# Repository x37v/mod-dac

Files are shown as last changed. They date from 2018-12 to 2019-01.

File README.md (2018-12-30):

# MOD-DAC

An 8 channel DAC Schematic/PCB project intended for modular use.
It should be able to give -5..5 or 0..5 or some other range within that.
It is intended to be driven by 3.3v signals from a micro controller, not included in this project.

This project is adapted from the [Mutable Instruments "Stages"](https://mutable-instruments.net/modules/stages/open_source/).
Thank you to [O. Gillet](https://mutable-instruments.net).

## License

<br /><span xmlns:dct="http://purl.org/dc/terms/" property="dct:title">MOD-DAC</span> by <a xmlns:cc="http://creativecommons.org/ns#" href="https://github.com/x37v/mod-dac" property="cc:attributionName" rel="cc:attributionURL">Alex Norman</a> is licensed under a <a rel="license" href="http://creativecommons.org/licenses/by-sa/4.0/">Creative Commons Attribution-ShareAlike 4.0 International License</a>.<br />Based on a work at <a xmlns:dct="http://purl.org/dc/terms/" href="https://mutable-instruments.net/modules/stages/open_source/" rel="dct:source">https://mutable-instruments.net/modules/stages/open_source/</a>.

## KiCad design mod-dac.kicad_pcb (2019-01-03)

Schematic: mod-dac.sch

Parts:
C13, C17, C18, C19, C20, C21, C22: 22u; C_0805_2012Metric_Pad1.33x1.40mm_HandSolder
C14, C15, C16: 1u; C_0805_2012Metric_Pad1.33x1.40mm_HandSolder
J1: digi in; PinHeader_1x04_P2.54mm_Vertical
J2: cv out; PinHeader_1x09_P2.54mm_Vertical
L1, L2, L3: BEAD; L_0603_1608Metric_Pad1.05x0.95mm_HandSolder
P1: MTA-156-4
TR1: VREF TRIM; trimmer
TR2: BIAS TRIM; trimmer
U4: DAC8168; TSSOP-14_4.4x5mm_P0.65mm
U5: LD2981; SOT-89-3_Handsoldering

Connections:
+15V: C18.1, C21.1, L2.1; also elsewhere on the board
-15V: C17.2, C22.2, L1.1; also elsewhere on the board
DIN: J1.2, U4.13
GND: C13.2, C14.2, C15.2, C16.2, C17.1, C18.2, C19.2, C20.2, C21.2, C22.1, J1.4, J2.9, P1.2, P1.3, TR1.3, TR2.3, U4.12, U5.2; also elsewhere on the board
unnamed: C19.1, L3.2, U5.3
unnamed: L1.2, P1.4
unnamed: L2.2, L3.1, P1.1
REFVCC: C13.1, C14.1, C20.1, TR1.1, TR2.1, U4.2, U5.1
SCLK: J1.1, U4.14
\SYNC: J1.3, U4.1
dac0: U4.3; also elsewhere on the board
dac1: U4.11; also elsewhere on the board
dac2: U4.4; also elsewhere on the board
dac3: U4.10; also elsewhere on the board
dac4: U4.5; also elsewhere on the board
dac5: U4.9; also elsewhere on the board
dac6: U4.6; also elsewhere on the board
dac7: U4.8; also elsewhere on the board
vbias: C16.1, TR2.2; also elsewhere on the board
vout0: J2.1; also elsewhere on the board
vout1: J2.2; also elsewhere on the board
vout2: J2.3; also elsewhere on the board
vout3: J2.4; also elsewhere on the board
vout4: J2.5; also elsewhere on the board
vout5: J2.6; also elsewhere on the board
vout6: J2.7; also elsewhere on the board
vout7: J2.8; also elsewhere on the board
vref: C15.1, TR1.2, U4.7

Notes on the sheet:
do we want a separate vreg for the reference voltages?

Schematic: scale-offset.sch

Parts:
C1, C2, C3, C4, C5, C6, C7, C8: 100p; C_0805_2012Metric_Pad1.33x1.40mm_HandSolder
C9, C10, C11, C12: 100n; C_0805_2012Metric_Pad1.33x1.40mm_HandSolder
R1, R2, R3, R4, R13, R14, R15, R16: 23.7k; R_0805_2012Metric_Pad1.33x1.40mm_HandSolder
R5, R6, R7, R8, R17, R18, R19, R20: 100k; R_0805_2012Metric_Pad1.33x1.40mm_HandSolder
R9, R10, R11, R12, R21, R22, R23, R24: 1k; R_0805_2012Metric_Pad1.33x1.40mm_HandSolder
U1, U2: TL074; TSSOP-14_4.4x5mm_P0.65mm

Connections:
+15V: C9.1, C11.1, U1.4 (V+), U2.4 (V+); also elsewhere on the board
-15V: C10.2, C12.2, U1.11 (V-), U2.11 (V-); also elsewhere on the board
GND: C9.2, C10.1, C11.2, C12.1; also elsewhere on the board
unnamed: C1.1, R9.2, U1.1
unnamed: C1.2, R1.1, R5.2, U1.2 (-)
unnamed: C2.1, R10.2, U1.7
unnamed: C2.2, R2.1, R6.2, U1.6 (-)
unnamed: C3.1, R11.2, U1.8
unnamed: C3.2, R3.1, R7.2, U1.9 (-)
unnamed: C4.1, R12.2, U1.14
unnamed: C4.2, R4.1, R8.2, U1.13 (-)
unnamed: C5.1, R21.2, U2.1
unnamed: C5.2, R13.1, R17.2, U2.2 (-)
unnamed: C6.1, R22.2, U2.7
unnamed: C6.2, R14.1, R18.2, U2.6 (-)
unnamed: C7.1, R23.2, U2.8
unnamed: C7.2, R15.1, R19.2, U2.9 (-)
unnamed: C8.1, R24.2, U2.14
unnamed: C8.2, R16.1, R20.2, U2.13 (-)
dac0: R16.2; also elsewhere on the board
dac1: R1.2; also elsewhere on the board
dac2: R15.2; also elsewhere on the board
dac3: R2.2; also elsewhere on the board
dac4: R14.2; also elsewhere on the board
dac5: R3.2; also elsewhere on the board
dac6: R13.2; also elsewhere on the board
dac7: R4.2; also elsewhere on the board
vbias: U1.3 (+), U1.5 (+), U1.10 (+), U1.12 (+), U2.3 (+), U2.5 (+), U2.10 (+), U2.12 (+); also elsewhere on the board
vout0: R5.1, R9.1; also elsewhere on the board
vout1: R6.1, R10.1; also elsewhere on the board
vout2: R7.1, R11.1; also elsewhere on the board
vout3: R8.1, R12.1; also elsewhere on the board
vout4: R17.1, R21.1; also elsewhere on the board
vout5: R18.1, R22.1; also elsewhere on the board
vout6: R19.1, R23.1; also elsewhere on the board
vout7: R20.1, R24.1; also elsewhere on the board

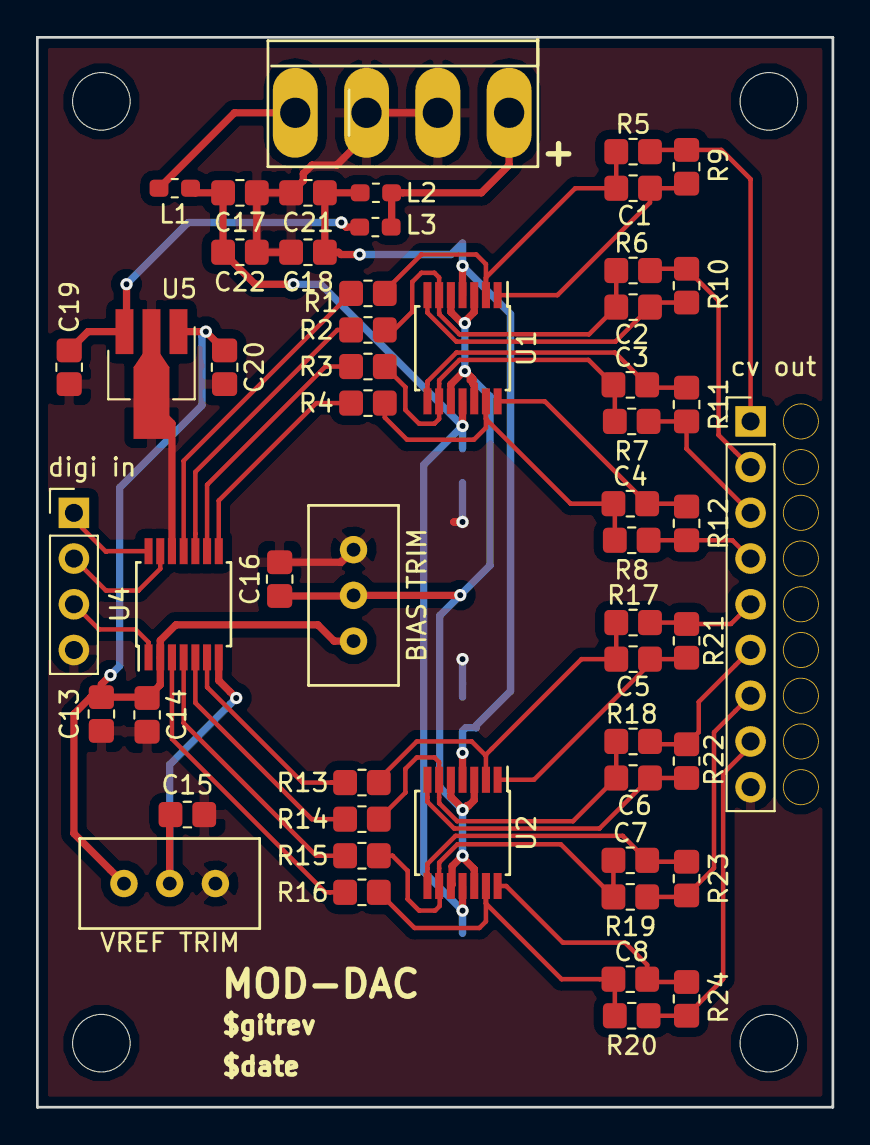
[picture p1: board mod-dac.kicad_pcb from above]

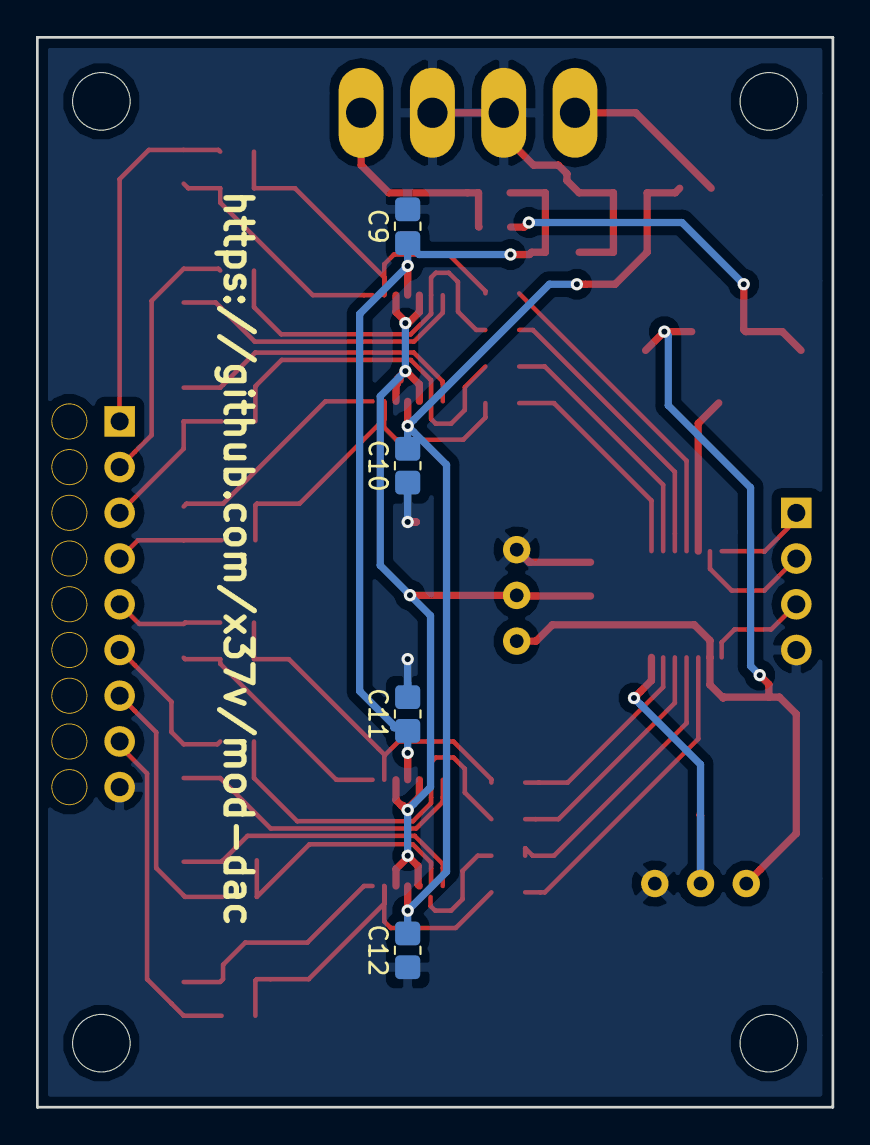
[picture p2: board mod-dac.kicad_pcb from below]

Board: 2 copper layers, 44.2 x 59.4 mm, 62 parts (4 on the bottom side), 44 nets.

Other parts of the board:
REF1, REF2, REF3, REF4: MountingHole_3.2mm_M3

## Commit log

2018-12-27 working simulation
    [mod-dac.kicad_pcb, mod-dac.sch]
2018-12-27 looking like the right values for ~4x gain
    [mod-dac.sch]
2018-12-28 updated with TL074
    [mod-dac.sch]
2018-12-28 major schematic progress
    [mod-dac.sch, scale-offset.sch]
2018-12-29 added 15v power
    [mod-dac.sch, scale-offset.sch]
2018-12-29 moved io around
    [mod-dac.sch, scale-offset.sch]
2018-12-29 fixed up power supply
    [mod-dac.sch]
2018-12-29 corrected cap orientation
    [mod-dac.sch]
2018-12-30 3.3v supply, also.. updated per stages
    [mod-dac.sch]
2018-12-30 removed polar parts
    [mod-dac.sch]
2018-12-30 no more F
    [scale-offset.sch]
2018-12-30 fixed incorrect chip number, assigned packages
    [mod-dac.sch, scale-offset.sch]
2018-12-30 rough bom
    [bom.csv]
2018-12-31 really rough layout
    [mod-dac.kicad_pcb]
2018-12-31 updated routing to more nicely map to chip
    [scale-offset.sch]
2018-12-31 more rough layout work
    [mod-dac.kicad_pcb]
2018-12-31 reordered connection for digital input
    [mod-dac.sch]
2018-12-31 more routing
    [mod-dac.kicad_pcb]
2018-12-31 i think i've routed the rest of the non gnd signals
    [mod-dac.kicad_pcb]
2018-12-31 edge cut
    [mod-dac.kicad_pcb]
2018-12-31 moved power a bit
    [mod-dac.kicad_pcb]
2018-12-31 corrected the edge cut
    [mod-dac.kicad_pcb]
2018-12-31 added strain relief
    [mod-dac.kicad_pcb]
2018-12-31 all hooked up, have text
    [mod-dac.kicad_pcb]
2019-01-03 updated text layout
    [mod-dac.kicad_pcb]
2019-01-03 moved text around
    align output info with pin 1, move githash
    [mod-dac.kicad_pcb]
